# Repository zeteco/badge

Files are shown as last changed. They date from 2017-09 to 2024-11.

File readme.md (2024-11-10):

# ZeTeCo-Badge

These are the PCB-Files ([KiCad](https://www.kicad.org/)) of the Badge for the [ZeTeCo-Camp](https://zeteco.ch/). The original design was made by [@bluetonyum](https://github.com/bluetonyum).

Please also visit the [Wiki-Page](https://wiki.zeteco.ch/wiki/Badge)

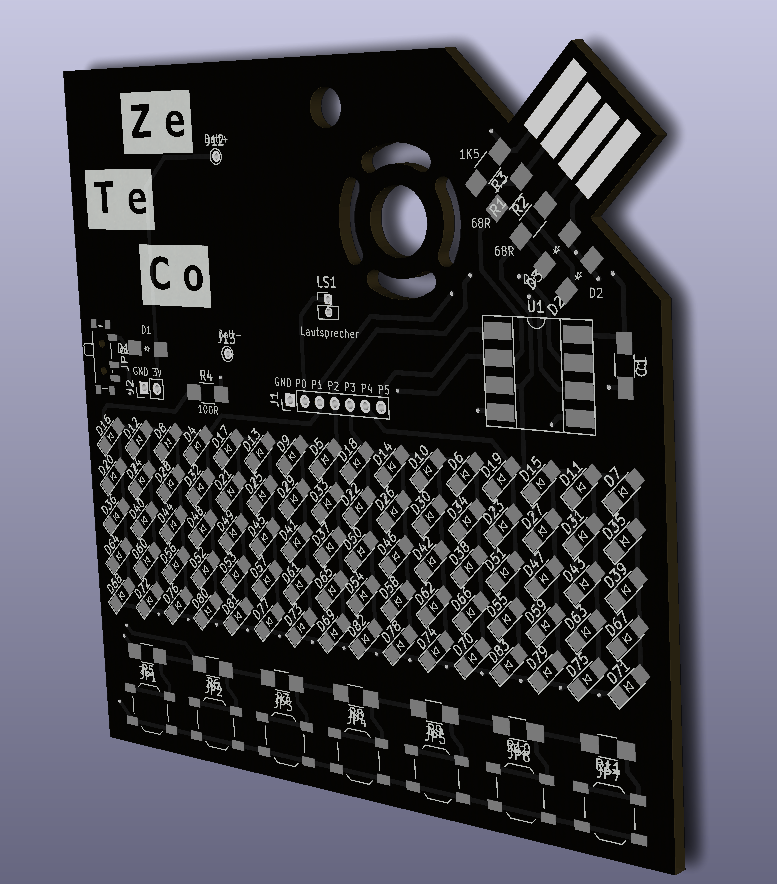
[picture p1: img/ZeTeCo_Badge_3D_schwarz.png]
Badge PCB


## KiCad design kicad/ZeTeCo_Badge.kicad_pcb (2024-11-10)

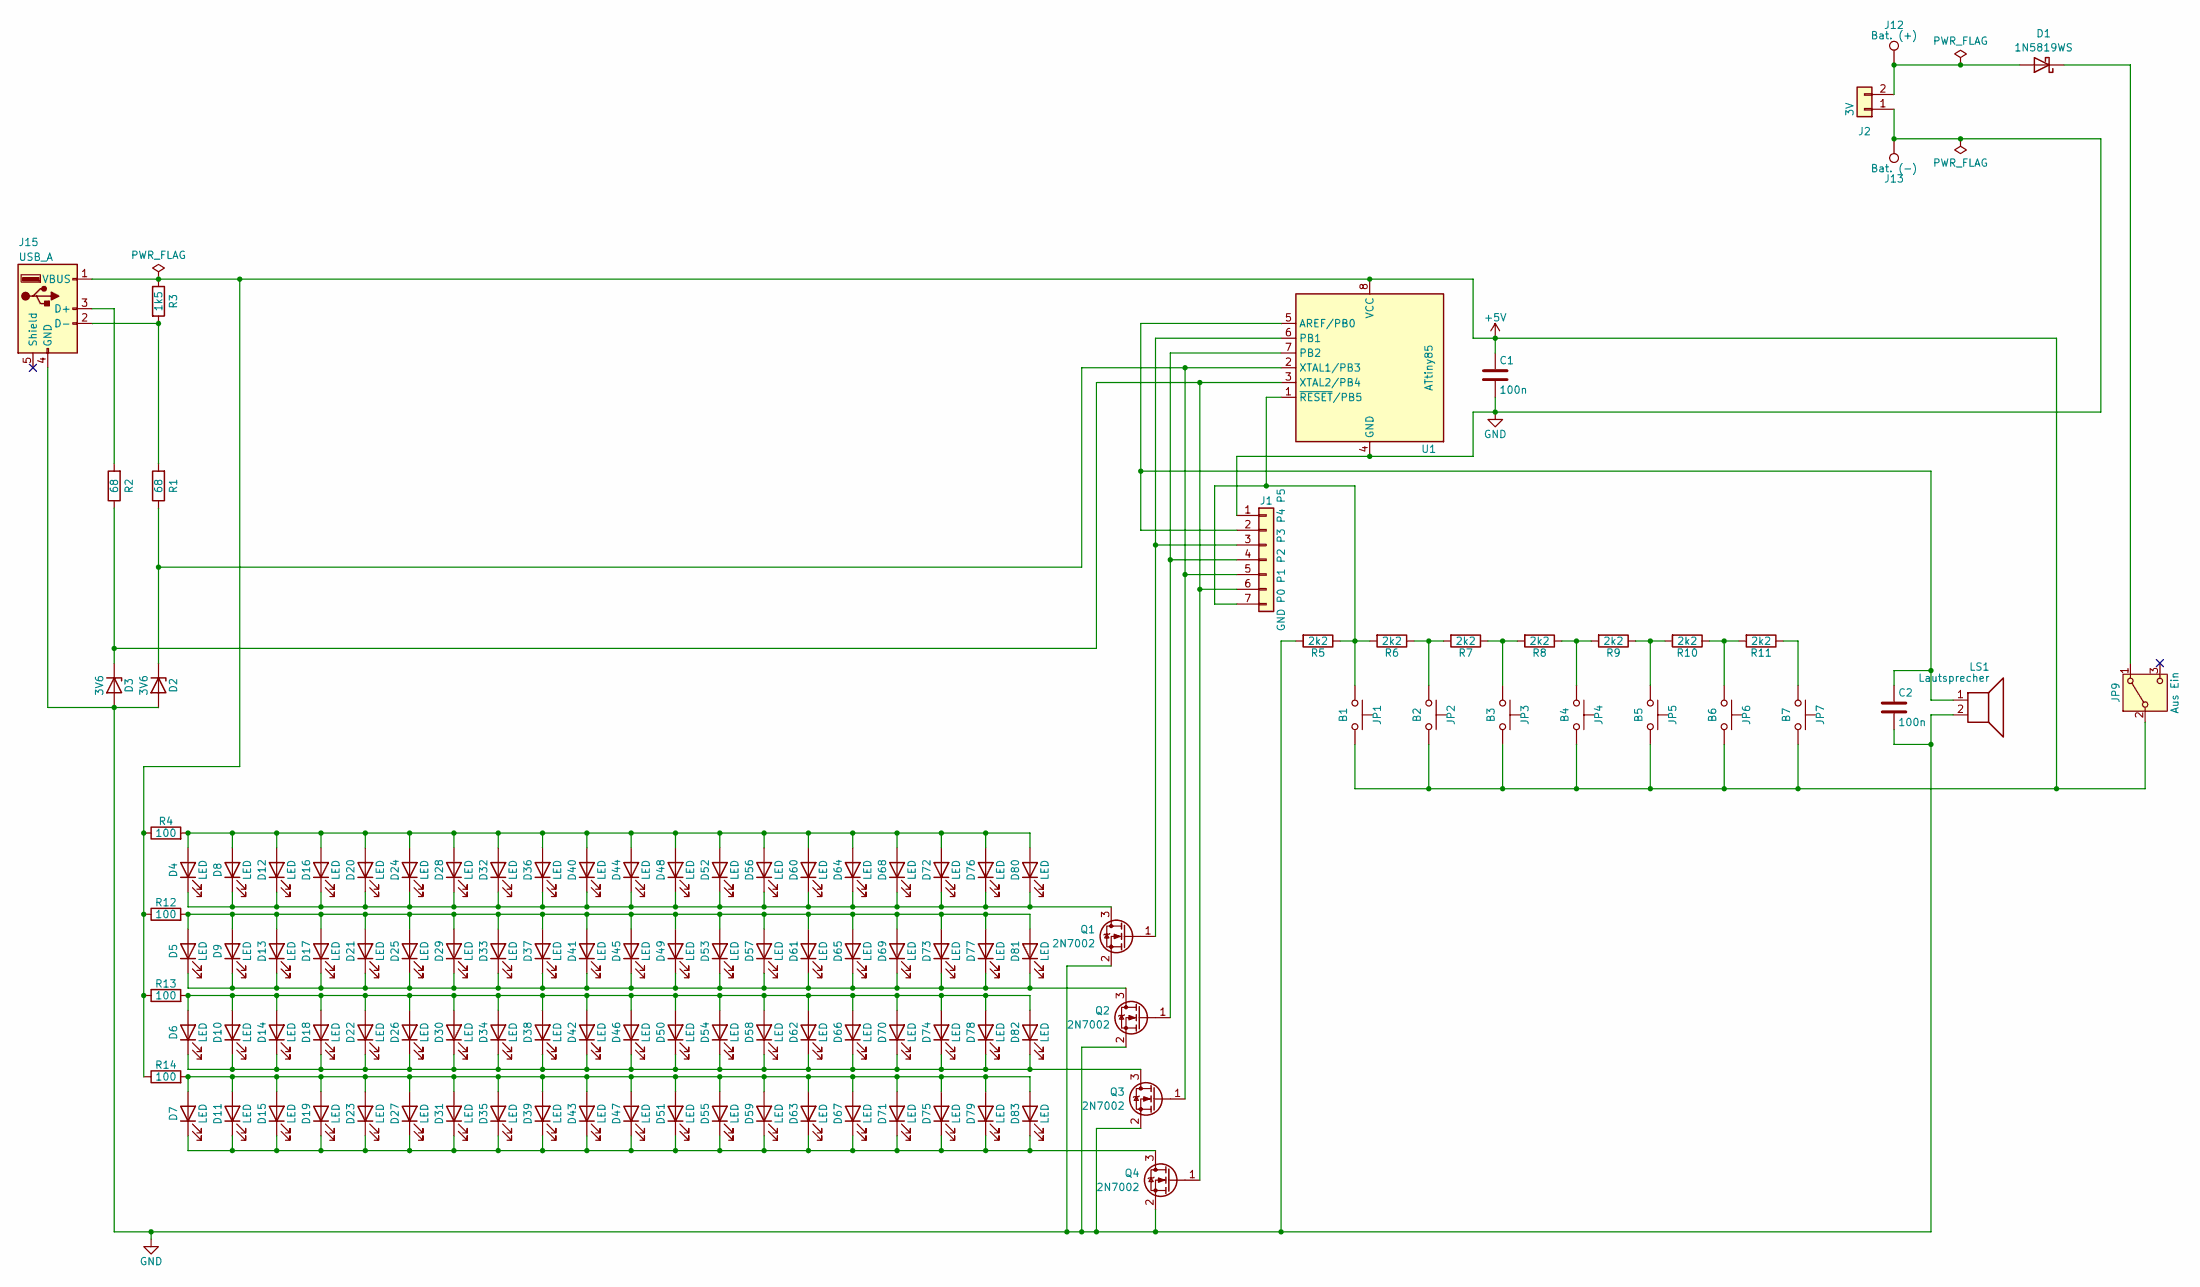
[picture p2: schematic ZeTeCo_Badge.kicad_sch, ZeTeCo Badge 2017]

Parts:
C1, C2: 100n; C_1206_3216Metric_Pad1.33x1.80mm_HandSolder
D1: 1N5819WS; D_1206_3216Metric_Pad1.42x1.75mm_HandSolder
D2, D3: 3V6; D_1206_3216Metric_Pad1.42x1.75mm_HandSolder
D4, D5, D6, D7, D8, D9, D10, D11, D12, D13, D14, D15, D16, D17, D18, D19, D20, D21, D22, D23, D24, D25, D26, D27, D28, D29, D30, D31, D32, D33, D34, D35, D36, D37, D38, D39, D40, D41, D42, D43, D44, D45, D46, D47, D48, D49, D50, D51, D52, D53, D54, D55, D56, D57, D58, D59, D60, D61, D62, D63, D64, D65, D66, D67, D68, D69, D70, D71, D72, D73, D74, D75, D76, D77, D78, D79, D80, D81, D82, D83: LED; LED_1206_3216Metric_Pad1.42x1.75mm_HandSolder
J1: GND P0 P1 P2 P3 P4 P5; PinHeader_1x07_P2.54mm_Vertical
J2: 3V; PinHeader_1x02_P2.54mm_Vertical
J12: Bat. (+); TestPoint_Keystone_5000-5004_Miniature
J13: Bat. (-); TestPoint_Keystone_5000-5004_Miniature
J15: USB_A; usb-PCB
JP1: B1; SW_SPST_TL3342
JP2: B2; SW_SPST_TL3342
JP3: B3; SW_SPST_TL3342
JP4: B4; SW_SPST_TL3342
JP5: B5; SW_SPST_TL3342
JP6: B6; SW_SPST_TL3342
JP7: B7; SW_SPST_TL3342
JP9: Aus Ein; SW_SPDT_PCM12
LS1: Lautsprecher; PinHeader_1x02_P2.54mm_Vertical
Q1, Q2, Q3, Q4: 2N7002; SOT-23
R1, R2: 68; R_1206_3216Metric_Pad1.30x1.75mm_HandSolder
R3: 1k5; R_1206_3216Metric_Pad1.30x1.75mm_HandSolder
R4, R12, R13, R14: 100; R_1206_3216Metric_Pad1.30x1.75mm_HandSolder
R5, R6, R7, R8, R9, R10, R11: 2k2; R_1206_3216Metric_Pad1.30x1.75mm_HandSolder
U1: ATtiny85; SOIC-8W_5.3x5.3mm_P1.27mm

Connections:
+5V: C1.1, J15.1 (VBUS), JP1.2, JP2.2, JP3.2, JP4.2, JP5.2, JP6.2, JP7.2, JP9.2 (B), R3.1, R4.1, R12.1, R13.1, R14.1, U1.8 (VCC)
GND: C1.2, C2.2, D2.2 (A), D3.2 (A), J1.1, J2.1, J13.1, J15.4 (GND), LS1.2, Q1.2 (S), Q2.2 (S), Q3.2 (S), Q4.2 (S), R5.2, U1.4 (GND)
unnamed: D1.2 (A), J2.2, J12.1
unnamed: D1.1 (K), JP9.1 (A)
unnamed: D2.1 (K), J1.5, Q3.1 (G), R1.1, U1.2 (XTAL1/PB3)
unnamed: D3.1 (K), J1.6, Q4.1 (G), R2.1, U1.3 (XTAL2/PB4)
unnamed: D6.2 (A), D10.2 (A), D14.2 (A), D18.2 (A), D22.2 (A), D26.2 (A), D30.2 (A), D34.2 (A), D38.2 (A), D42.2 (A), D46.2 (A), D50.2 (A), D54.2 (A), D58.2 (A), D62.2 (A), D66.2 (A), D70.2 (A), D74.2 (A), D78.2 (A), D82.2 (A), R13.2
unnamed: D6.1 (K), D10.1 (K), D14.1 (K), D18.1 (K), D22.1 (K), D26.1 (K), D30.1 (K), D34.1 (K), D38.1 (K), D42.1 (K), D46.1 (K), D50.1 (K), D54.1 (K), D58.1 (K), D62.1 (K), D66.1 (K), D70.1 (K), D74.1 (K), D78.1 (K), D82.1 (K), Q3.3 (D)
unnamed: D7.2 (A), D11.2 (A), D15.2 (A), D19.2 (A), D23.2 (A), D27.2 (A), D31.2 (A), D35.2 (A), D39.2 (A), D43.2 (A), D47.2 (A), D51.2 (A), D55.2 (A), D59.2 (A), D63.2 (A), D67.2 (A), D71.2 (A), D75.2 (A), D79.2 (A), D83.2 (A), R14.2
unnamed: D7.1 (K), D11.1 (K), D15.1 (K), D19.1 (K), D23.1 (K), D27.1 (K), D31.1 (K), D35.1 (K), D39.1 (K), D43.1 (K), D47.1 (K), D51.1 (K), D55.1 (K), D59.1 (K), D63.1 (K), D67.1 (K), D71.1 (K), D75.1 (K), D79.1 (K), D83.1 (K), Q4.3 (D)
unnamed: D4.2 (A), D8.2 (A), D12.2 (A), D16.2 (A), D20.2 (A), D24.2 (A), D28.2 (A), D32.2 (A), D36.2 (A), D40.2 (A), D44.2 (A), D48.2 (A), D52.2 (A), D56.2 (A), D60.2 (A), D64.2 (A), D68.2 (A), D72.2 (A), D76.2 (A), D80.2 (A), R4.2
unnamed: D4.1 (K), D8.1 (K), D12.1 (K), D16.1 (K), D20.1 (K), D24.1 (K), D28.1 (K), D32.1 (K), D36.1 (K), D40.1 (K), D44.1 (K), D48.1 (K), D52.1 (K), D56.1 (K), D60.1 (K), D64.1 (K), D68.1 (K), D72.1 (K), D76.1 (K), D80.1 (K), Q1.3 (D)
unnamed: D5.2 (A), D9.2 (A), D13.2 (A), D17.2 (A), D21.2 (A), D25.2 (A), D29.2 (A), D33.2 (A), D37.2 (A), D41.2 (A), D45.2 (A), D49.2 (A), D53.2 (A), D57.2 (A), D61.2 (A), D65.2 (A), D69.2 (A), D73.2 (A), D77.2 (A), D81.2 (A), R12.2
unnamed: D5.1 (K), D9.1 (K), D13.1 (K), D17.1 (K), D21.1 (K), D25.1 (K), D29.1 (K), D33.1 (K), D37.1 (K), D41.1 (K), D45.1 (K), D49.1 (K), D53.1 (K), D57.1 (K), D61.1 (K), D65.1 (K), D69.1 (K), D73.1 (K), D77.1 (K), D81.1 (K), Q2.3 (D)
unnamed: C2.1, J1.2, LS1.1, U1.5 (AREF/PB0)
unnamed: J1.3, Q1.1 (G), U1.6 (PB1)
unnamed: J1.4, Q2.1 (G), U1.7 (PB2)
unnamed: J1.7, JP1.1, R5.1, R6.2, U1.1 (~RESET/PB5)
unnamed: J15.3 (D+), R2.2
unnamed: J15.2 (D-), R1.2, R3.2
unnamed: JP2.1, R6.1, R7.2
unnamed: JP3.1, R7.1, R8.2
unnamed: JP4.1, R8.1, R9.2
unnamed: JP5.1, R9.1, R10.2
unnamed: JP6.1, R10.1, R11.2
unnamed: JP7.1, R11.1

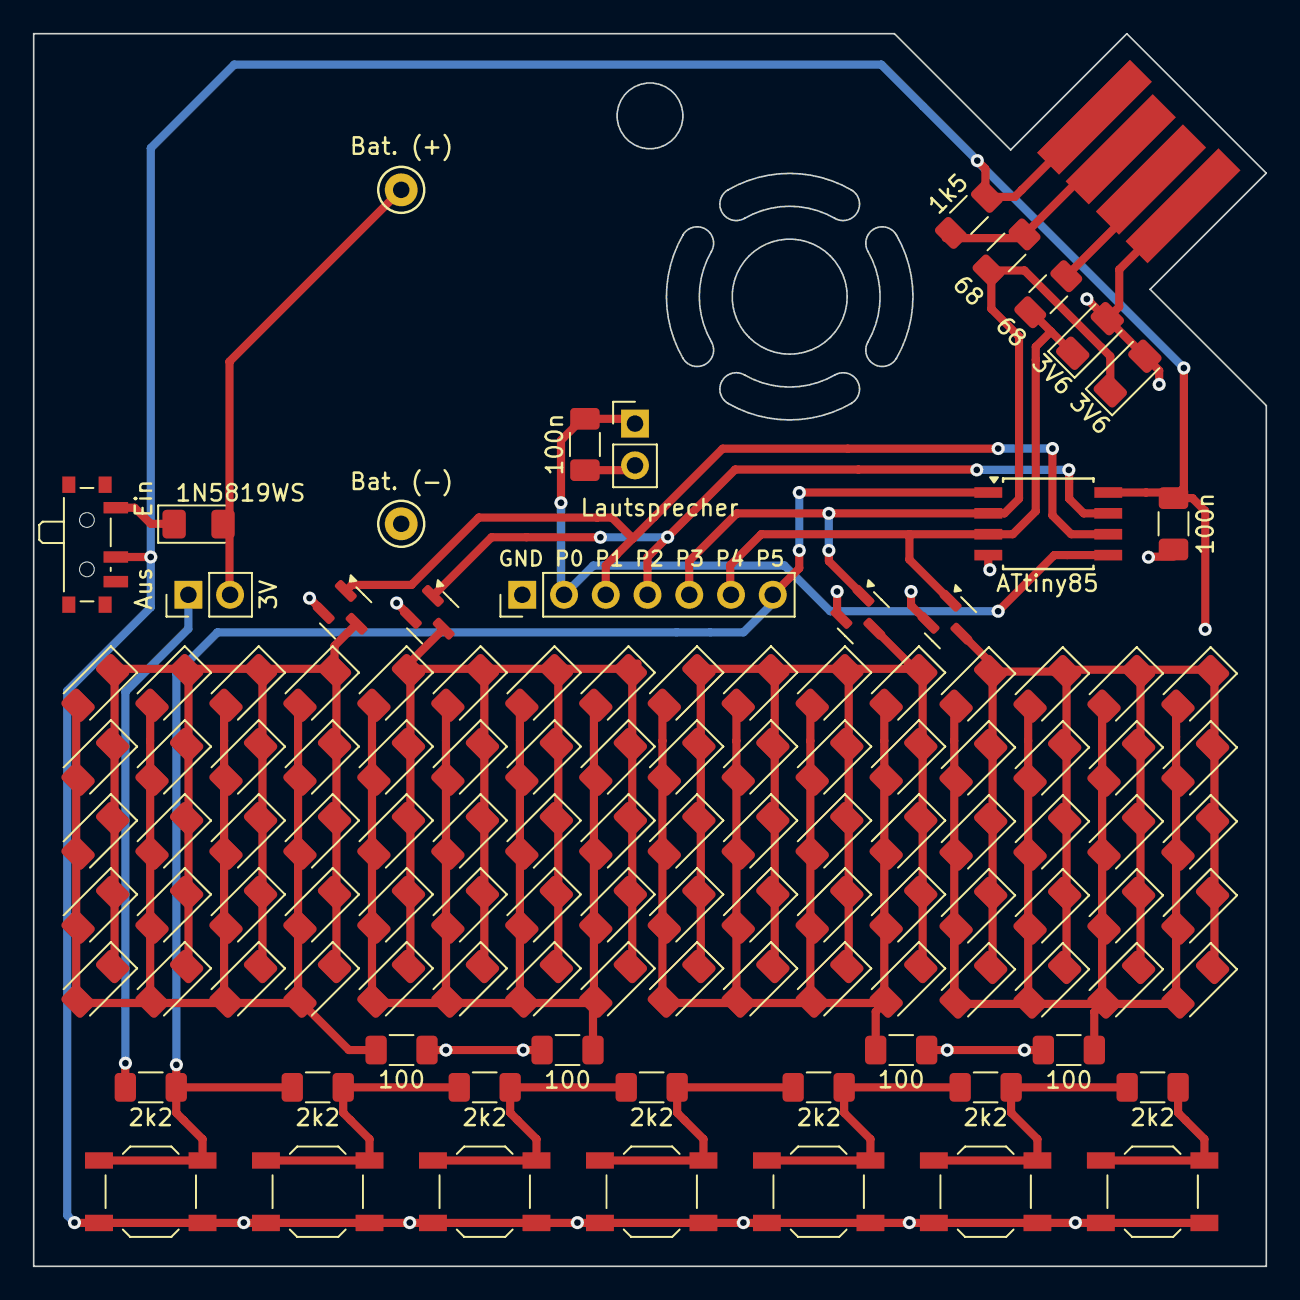
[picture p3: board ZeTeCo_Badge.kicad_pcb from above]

Board: 2 copper layers, 75.0 x 75.0 mm, 118 parts (0 on the bottom side), 26 nets.

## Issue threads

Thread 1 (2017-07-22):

Dead Link in Fahrplan

birdy1976, 2017-07-22:
The link „Badge im Wiki“ [1] in „ZeTeCo Badge“ [2] should point to [3].

[1] http://badge.zeteco.ch/
[2] https://fahrplan.zeteco.ch/events/64.html
[3] https://wiki.zeteco.ch/wiki/Badge

signalwerk, 2017-07-25:
@birdy1976 danke für dein feedback. da war was krumm. sollte aber nun wieder gehen! sobald tony mir noch die badge-materialien gegeben hat, werde ich die hier auch noch hoch laden.

Closed 2017-07-25.

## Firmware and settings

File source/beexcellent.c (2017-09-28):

// Source: https://wiki.zeteco.ch/wiki/Badge#Be_excellent_.28to_each_other.29

#include <avr/pgmspace.h>

/*
 * Copyleft 2017 by Ivo Blöchliger, vorname@bloechligair.ch
 */

/*
 * 8kHz samplerate, runlength encoded (255,x means x times 127)
 */

const unsigned char samples[] PROGMEM = {
130,127,127,133,124,127,130,122,255,4,131,131,133,137,139,141,144,147,149,152,155,143,153,156,145,141,135,132,127,121,116,111,108,107,104,102,101,103,
110,106,108,106,120,119,113,119,127,131,127,130,127,134,138,132,127,136,133,130,127,127,130,132,127,122,127,130,255,4,130,127,127,124,127,121,121,124,120,119,
120,122,122,122,127,127,137,135,134,137,165,151,147,155,170,161,161,145,149,164,147,106,133,137,104,91,114,104,92,83,96,112,102,97,105,130,115,118,130,135,
130,136,136,138,136,133,138,127,131,127,133,123,122,255,6,130,131,127,130,130,130,255,4,122,117,121,118,117,114,116,122,123,115,131,141,127,136,160,148,150,
160,158,168,142,150,160,139,103,154,109,96,108,109,85,98,96,107,101,101,127,118,116,138,136,127,142,140,138,137,137,135,130,127,130,123,123,124,122,121,122,
124,124,127,127,130,130,132,133,134,132,130,132,127,124,124,123,117,117,114,119,110,113,127,115,117,143,127,135,154,148,154,151,167,153,140,157,149,98,158,100,
100,114,98,89,104,101,106,102,127,123,114,146,132,133,148,141,137,142,137,135,127,133,127,122,124,121,118,121,121,121,122,255,3,131,133,134,133,136,136,131,
131,133,122,124,122,116,112,111,117,103,112,124,110,120,151,118,154,156,157,158,166,172,149,144,178,104,131,144,76,111,103,81,88,95,96,95,100,137,99,139,
143,131,145,153,140,146,144,142,132,132,134,119,124,122,116,117,119,118,119,122,127,127,130,134,136,136,136,139,136,130,134,130,117,127,115,111,107,112,106,101,
117,123,99,149,134,130,168,157,163,164,182,166,151,164,170,76,180,82,92,103,86,71,88,90,96,83,127,117,104,158,130,140,155,151,145,149,148,142,127,141,
124,119,124,116,112,115,116,116,118,124,127,127,135,139,140,139,144,142,133,134,137,112,123,116,101,103,103,102,92,107,123,97,134,160,114,183,170,174,177,197,
183,166,153,206,56,175,102,64,101,81,59,71,80,85,70,104,133,77,165,133,143,157,165,152,155,156,153,127,144,130,114,122,114,107,110,113,112,114,123,127,
127,137,142,141,142,147,143,134,136,136,108,124,111,95,100,101,92,92,104,127,87,150,154,119,194,174,178,187,206,184,171,161,210,39,203,70,73,89,74,50,
63,78,82,60,117,122,81,173,127,149,159,166,154,155,160,150,127,148,124,115,123,112,107,111,113,112,115,255,3,140,143,142,145,149,142,131,141,127,107,124,
104,94,98,101,88,96,106,127,79,180,127,145,188,173,174,189,198,179,157,185,173,57,219,34,107,81,73,50,72,79,77,68,136,97,110,170,120,157,159,159,
150,156,156,139,135,144,116,121,122,109,110,114,113,114,119,127,127,131,137,140,140,140,144,140,127,139,127,112,123,109,101,103,107,98,99,116,127,89,175,120,
150,175,167,165,179,182,172,141,189,142,85,198,42,120,85,81,65,86,87,84,87,137,95,127,160,115,159,150,151,145,153,146,135,137,137,117,127,121,111,117,
116,114,119,122,124,127,132,134,139,140,137,141,141,127,137,127,113,121,113,103,105,108,105,96,120,127,91,172,122,147,171,165,162,176,176,171,134,192,127,94,
191,43,127,86,83,71,91,90,87,96,135,96,131,157,112,163,144,148,143,151,141,134,138,133,117,127,120,113,120,117,116,121,123,124,127,131,132,137,137,133,
139,135,127,136,122,118,121,116,106,113,109,114,95,144,98,127,151,124,153,162,159,156,174,162,160,127,201,62,170,109,82,121,92,88,93,101,95,96,116,123,
97,156,119,134,152,136,142,146,141,135,137,136,255,3,118,123,123,119,123,127,124,127,131,127,133,134,127,134,132,123,127,123,116,116,120,108,111,118,116,101,
151,102,142,146,136,151,160,159,150,169,161,145,138,184,61,188,84,104,117,93,88,104,97,94,105,113,112,106,150,103,145,139,127,142,144,133,140,139,132,133,
134,127,127,131,124,255,4,130,127,127,130,124,127,127,121,120,122,118,112,122,116,112,127,124,108,151,115,142,144,143,145,155,157,143,159,156,138,137,168,77,
174,92,111,120,99,97,112,100,100,110,110,112,110,138,104,141,130,127,140,137,131,141,136,132,136,134,130,132,132,127,130,255,4,124,127,127,121,123,122,119,
118,122,115,117,127,115,119,134,116,131,141,123,149,140,147,144,157,146,145,155,147,124,165,116,121,151,87,131,110,99,108,110,98,110,109,114,108,127,117,118,
138,120,132,137,127,135,138,130,135,135,131,132,134,127,127,131,255,255,127,255,255,127,255,255,127,255,42,130,127,130,131,127,130,123,121,127,127,114,127,134,
139,139,132,137,140,108,98,131,122,132,141,165,179,168,109,137,123,76,74,100,113,131,127,135,164,131,111,120,120,111,118,119,135,138,127,131,135,127,124,127,
122,127,124,124,127,131,130,132,132,127,132,120,119,127,123,108,132,136,146,143,135,145,144,91,88,135,117,138,150,191,207,180,95,151,110,47,47,90,106,135,
121,145,182,127,103,117,115,102,115,115,142,141,127,134,139,127,123,124,121,123,123,123,127,131,131,132,133,127,132,127,115,123,127,108,122,139,143,151,137,140,
153,109,70,123,127,127,151,180,219,210,118,122,147,48,34,67,101,124,132,127,187,154,100,111,117,102,108,114,130,150,127,131,141,131,120,127,121,121,121,122,
127,130,133,134,135,132,127,135,115,113,127,121,97,136,142,159,153,140,156,153,65,66,140,111,148,166,234,252,205,75,168,91,0,6,75,96,141,116,160,209,
122,91,112,107,89,110,110,152,145,127,138,146,122,122,124,118,119,119,122,127,132,134,135,136,130,132,131,109,117,127,107,105,145,145,166,146,144,166,127,39,
99,137,115,163,190,254,250,152,93,177,40,0,28,90,110,142,115,195,185,97,100,115,98,94,111,121,161,132,127,144,139,117,127,120,118,119,120,124,130,135,
137,138,137,127,139,118,104,121,127,86,127,148,164,169,144,157,174,71,25,134,115,138,174,245,254,229,91,144,127,9,0,59,92,132,127,139,211,144,89,109,
112,91,106,110,141,153,127,135,146,127,120,127,119,119,120,122,127,130,133,134,135,131,130,134,114,115,127,118,101,139,141,159,147,139,156,145,64,81,140,113,
150,165,229,241,186,80,171,80,13,19,85,101,141,115,166,196,115,96,114,108,94,113,114,152,139,127,138,141,121,124,123,120,120,120,124,127,131,135,136,135,
131,131,134,110,114,127,113,97,142,143,165,151,142,163,143,49,78,142,111,156,174,251,252,185,78,177,69,2,12,84,100,143,112,176,199,110,94,114,104,92,
112,115,157,138,127,140,143,120,127,122,120,119,117,124,127,127,135,135,133,133,127,135,119,113,124,127,98,127,140,153,154,139,149,158,87,61,134,118,136,158,
207,239,214,92,145,124,24,16,71,98,132,124,141,198,138,94,113,113,97,110,114,142,147,127,134,141,127,122,127,122,122,119,122,127,127,131,137,133,133,131,
130,134,115,116,127,118,100,136,140,157,148,139,155,144,68,84,140,114,149,162,222,230,179,85,167,83,26,33,90,104,139,116,163,185,115,101,116,109,100,116,
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

volatile int pos=0;

/*
 * Setting up the timers, Timer 0 62kHz 8bit PWM as carrier
 * Timer 1, 8kHz for interrupt to set duty cycle (and decode rle)
 */

void setup() {
  for (int i=0; i<5; i++) {
    pinMode(i, OUTPUT);
  }
  // Timer 0
  TCCR0A = 0b10000011;  //
  TCCR0B = 0b001;       // No prescaling 62kHz carrier
  OCR0A = 8;            // 0..255 pwm on output OC0A pin  (OC0A is needed!)

  // Timer 1
  cli();

    TCCR1=0;
    TCNT1 = 0;                  //zero the timer
    GTCCR = _BV(PSR1);          //reset the prescaler
    OCR1A=255;           //contador CTC, tiene un tamaño de 2^8-1=255
    OCR1C=255;
    TCCR1 = 0b0100;    // Prescaler 7812Hz
    TIMSK=(1<<OCIE1A); //para habilitar la comparacion Output Compare A Match (vector interrupcion)

    sei();
}

void pwmOn() {
  pos = 0;
  TCCR0A = 0b10000011;
}
void pwmOff() {
  TCCR0A = 0;
}

volatile unsigned char rle=0;
volatile unsigned long myMillis=0;
ISR(TIMER1_COMPA_vect) {
  myMillis++;
  if (TCCR0A) {
    if (rle>0) {
      OCR0A=127;
      rle--;
    } else {
      int v = pgm_read_byte(&(samples[pos]));
      pos++;
      if (v==255) {
        rle = pgm_read_byte(&(samples[pos]));
        pos++;
        OCR0A = 127;
      } else {
        OCR0A = v;
      }
    }
    if (pos>=sizeof(samples)) {
      pos=0;
      pwmOff();
    }
  }
}

/*
 * delay ist not working anymore, so here is myDelay
 */

void myDelay(int ms) {
  ms*=8;
  long start = myMillis;
  while (start+ms-myMillis>0);
}

// returns the button number pressed, or zero for none pressed
int readButtons() {
  int c = analogRead(A0); // get the analog value from ADC0 (on pin 5)
  if (c>600) {
    return 1;
  } else if (c>400) {
    return 2; // button 2 pressed
  } else if (c>300) {
    return 3; // button 3 pressed
  } else if (c>240) {
     return 4; // button 4 pressed
  } else if (c>180) {
     return 5; // button 5 pressed
  } else if (c>160) {
     return 6;  // button 6 pressed
  } else if (c>100) {
    return 7;
  }
  return 0;
}

/*
 * Did not manage (for some unknown reason) to use my software pwm... something fishy in this whole sketch.
 */

void roller() {
  while (true) {
    for (int i=1; i<7; i++) {
      digitalWrite(i>4? 8-i : i, HIGH);
      myDelay(200);
      digitalWrite(i>4? 8-i : i,LOW);
      if (readButtons()!=0) return;
    }
  }
}

void loop() {
  roller();
  pwmOn();
  while(readButtons()!=0) {
    for (int i=0; i<4; i++) {
      digitalWrite(i+1,HIGH);
      myDelay(1);
      digitalWrite(i+1,LOW);
    }
  }
}

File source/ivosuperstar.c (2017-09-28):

// Source from; https://wiki.zeteco.ch/wiki/Badge#Ivos_Code
#include <avr/pgmspace.h>

/*
 * Copyleft 2017 by Ivo Blöchliger, Kontakt: vorname@bloechligair.ch
 */


// returns the button number pressed, or zero for none pressed
int readButtons() {
  int c = analogRead(A0); // get the analog value from ADC0 (on pin 5)
  if (c>600) {
    return 1;
  } else if (c>400 && c<550) {
    return 2; // button 2 pressed
  } else if (c>300 && c<400) {
    return 3; // button 3 pressed
  } else if (c>240 && c<290) {
     return 4; // button 4 pressed
  } else if (c>180 && c<230) {
     return 5; // button 5 pressed
  } else if (c>160 && c<175) {
     return 6;  // button 6 pressed
  } else if (c>100 && c<155) {
    return 7;
  }
  return 0;
}

void setup() {
  // Set sound and letter pins
  for (int i=0; i<5; i++) {
    pinMode(i,OUTPUT);
  }
}

// Poor mans PWM (you should not take time to do much else)
// To use, set duty[0] to duty[3] to values between 0.0 and 1.0
// and call this function continously
float duty[] = {1.0,1.0,1.0,1.0};
void pwmLoop() {
  for (int i=0; i<4; i++) {
    int us = duty[i]*duty[i]*500;  // quadratic function in order to compensate for logarithmic perception of light intensity
    digitalWrite(i+1, HIGH);
    delayMicroseconds(us);
    digitalWrite(i+1, LOW);
    delayMicroseconds(500-us);
  }
}

int periods[48] = {1132, 1069, 1009, 952, 898, 848, 800, 755, 713, 673, 635, 600, 566, 534, 504, 476, 449, 424, 400, 377, 356, 336, 317, 300, 283, 267, 252, 238, 224, 212, 200, 188, 178, 168, 158, 150, 141, 133, 126, 119, 112, 106, 100, 94, 89, 84, 79, 75};

void myTones(int duration, int t1, int t2, int t3) {
  int limits[3]={-1,-1,-1};
  if (t1>-24 && t1<=24) limits[0]=periods[t1+23];
  if (t2>-24 && t2<=24) limits[1]=periods[t2+23];
  if (t3>-24 && t3<=24) limits[2]=periods[t3+23];

  int counters[3] = {0,0,0};
  long start = millis();
  long tleft = start+duration-millis();
  while (tleft>0) {
    tleft = start+duration-millis();
    for (int k=0; k<3; k++) {
      counters[k]++;
      if (counters[k]==limits[k]) {
        counters[k]=0;
        digitalWrite(0,HIGH);
      }
      if (counters[k]==17) {
        digitalWrite(0,LOW);
      }
    }
  }
}

void america() {

  myTones(160, 0,4,7);
  delay(40);
  if (readButtons()>0) return;
  myTones(160, 0,4,7);
  delay(40);
  if (readButtons()>0) return;
  myTones(160, 0,4,7);
  delay(40);
  if (readButtons()>0) return;
  myTones(160, 4,7,12);
  delay(40);
  if (readButtons()>0) return;
  myTones(160, 4,7,12);
  delay(40);
  if (readButtons()>0) return;
  myTones(160, 4,7,12);
  delay(40);
  if (readButtons()>0) return;

  myTones(260, 0,5,9);
  delay(40);
  if (readButtons()>0) return;
  myTones(260, 0,5,-3);
  delay(40);
  if (readButtons()>0) return;
  myTones(260, 0,-7,-3);
  delay(40);
  if (readButtons()>0) return;

  myTones(160, 0,4,7);
  if (readButtons()>0) return;
  delay(40);
  myTones(160, 0,4,7);
  delay(40);
  if (readButtons()>0) return;
  myTones(160, 0,4,7);
  delay(40);
  if (readButtons()>0) return;
  myTones(160, 4,7,12);
  delay(40);
  if (readButtons()>0) return;
  myTones(160, 4,7,12);
  delay(40);
  if (readButtons()>0) return;
  myTones(160, 4,7,12);
  delay(40);
  if (readButtons()>0) return;

  myTones(260, 14,11,7);
  delay(40);
  if (readButtons()>0) return;
  myTones(260, 11,7,2);
  delay(40);
  if (readButtons()>0) return;
  myTones(260, -1,2,7);
  delay(40);
  if (readButtons()>0) return;



  myTones(160,10,7,3);
  delay(40);
  if (readButtons()>0) return;
  myTones(160,10,7,3);
  delay(40);
  if (readButtons()>0) return;
  myTones(160,10,7,3);
  delay(40);
  if (readButtons()>0) return;
  myTones(160,10,7,15);
  delay(40);
  if (readButtons()>0) return;
  myTones(160,10,7,15);
  delay(40);
  if (readButtons()>0) return;
  myTones(160,10,7,15);
  delay(40);
  if (readButtons()>0) return;

  myTones(260, 14,10,5);
  delay(40);
  if (readButtons()>0) return;
  myTones(260, 10,5,2);
  delay(40);
  if (readButtons()>0) return;
  myTones(260, 5,2,-2);
  delay(40);
  if (readButtons()>0) return;

  myTones(160,3,0,-4);
  delay(40);
  if (readButtons()>0) return;
  myTones(160,3,0,-4);
  delay(40);
  if (readButtons()>0) return;
  myTones(160,3,0,-4);
  delay(40);
  if (readButtons()>0) return;
  myTones(160,0,3,8);
  delay(40);
  if (readButtons()>0) return;
  myTones(160,0,3,8);
  delay(40);
  if (readButtons()>0) return;
  myTones(160,0,3,8);
  delay(40);
  if (readButtons()>0) return;

  myTones(260, 7,2,-1);
  delay(40);
  if (readButtons()>0) return;
  myTones(260, 2,-1,-5);
  delay(40);
  if (readButtons()>0) return;
  myTones(260, -1,-5,-10);
  delay(40);
  if (readButtons()>0) return;

}

void fader() {
  int counter=0;
  while (readButtons()==0) {
    counter++;
    if (counter>1000) counter=0;
    duty[0] = abs(500-counter)/500.0;
    for (int i=1; i<4; i++) {
      duty[i] = duty[0];
    }
    pwmLoop();
  }
}

void roller(int period) {
  int counter=0;
  while (readButtons()==0) {
    counter++;
    if (counter>2*period) counter=0;
    for (int i=0; i<4; i++) {
      duty[i] = abs(period-((counter+2*period-i*period/2)%(2*period)))/(1.0*period);
    }
    pwmLoop();
  }
}

void fullpower(int period) {
  int pin=1;
  while (readButtons()==0) {
    digitalWrite(pin, HIGH);
    delay(period);
    digitalWrite(pin, LOW);
    pin+=1;
    if (pin==5) pin=1;
  }
}

// from http://www.mariopiano.com/mario-sheet-music-overworld-main-theme.html

const signed char mario[][4] PROGMEM = {{-10,6,16,4},
    {-10,6,16,4},
    {100,100,100,3},
    {-10,6,16,4},
    {100,100,100,3},
    {-10,6,12,4},
    {-10,6,16,4},
    {100,100,100,3},
    {7,11,19,4},
    {100,100,100,9},
    {7,-5,100,4},
    {100,100,100,9},
    {-5, 4, 12,3},  // Start Line 2, Index 12
    {100,100,100,6},
    {-8,0,7,3},
    {100,100,100,6},
    {-12,-5,4,3},
    {100,100,100,6},
    {-7,0,9,3},
    {100,100,100,3},
    {-5,2,11,3},
    {100,100,100,3},
    {-6,1,10,3},
    {-7,0,9,3},
    {100,100,100,3},
    {-8,0,7,4},
    {0,7,16,4},
    {4,11,19,4},
    {5,12,21,3},
    {100,100,100,3},
    {2, 9, 17, 3},
    {4,11,19,3},
    {100,100,100,3},
    {0,9,16,3},
    {100,100,100,3},
    {-3,4,12,3},
    {-1,5,14,3},
    {-5,2,11,3},
    {100,100,100,6},  // Index 38
/*    {-12,100,100,3},  // Page 2
    {100,100,100,6},
    {16, 19,100,3},
    {15,18,-8,3},
    {14,17,100,3},
    {11,15,100,3},
    {-5,100,100,3},
    {0,12,16,3},
    {100,100,100,3},
    {17,19,24,3},
    {100,100,100,3},
    {17,19,24,3},
    {17,19,24,3}, // INDEX 51
    {100,100,100,3},
    {-5,100,100,3},
    {100,100,100,3} // INDEX 54, end of line 2 (page 2)    */
    };
// C 0, D 2, E 4, F 5, G 7, A 9, H 11
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

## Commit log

2017-09-28 MOD: initial commit
    [ZeTeCo_Badge-B.Cu.gbr, ZeTeCo_Badge-B.Mask.gbr, ZeTeCo_Badge-B.SilkS.gbr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]
2024-11-05 Fix permissions
    [ZeTeCo_Badge-B.Cu.gbr, ZeTeCo_Badge-B.Mask.gbr, ZeTeCo_Badge-B.SilkS.gbr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]
2024-11-06 Clean up backup and manufacturing files
    [ZeTeCo_Badge-B.Cu.gbr, ZeTeCo_Badge-B.Mask.gbr, ZeTeCo_Badge-B.SilkS.gbr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]
2024-11-06 Update, cleanup and redesign PCB, add MOSFETs
    [ZeTeCo_Badge.kicad_pcb, ZeTeCo_Badge.kicad_sch, ZeTeCo_Badge.sch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]
2024-11-07 Replace PCB text with component values on silkscreen
    [ZeTeCo_Badge.kicad_pcb, ZeTeCo_Badge.kicad_sch]
